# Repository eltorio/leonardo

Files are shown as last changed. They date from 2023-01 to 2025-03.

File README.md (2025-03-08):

# Leonardo
Arduino Leonardo schematic ported to Kicad

# Star the project

**If you appreciate my work, please consider giving it a star! 🤩**

# Kicad 8
The design has been ported to Kicad 8.  
* DRC shows no error nor warning on PCB.
* All selected parts are easily availables.
* All parts contains 3 additional fields
    * Manufacturer containing the name of the manufacturer
    * Manufacturer_ref containing the part real reference
    * Digikey_ref containing a Digikey part number

NM, DNP parts are parts not mounted

# Why
Because I need to adapt the Leonardo design to include other functionalities my first work is to port the very good Arduino Leonardo rev3d to Kicad 6.  

# Crystal
16MHz Crystal is not yet selected…

# Schematic
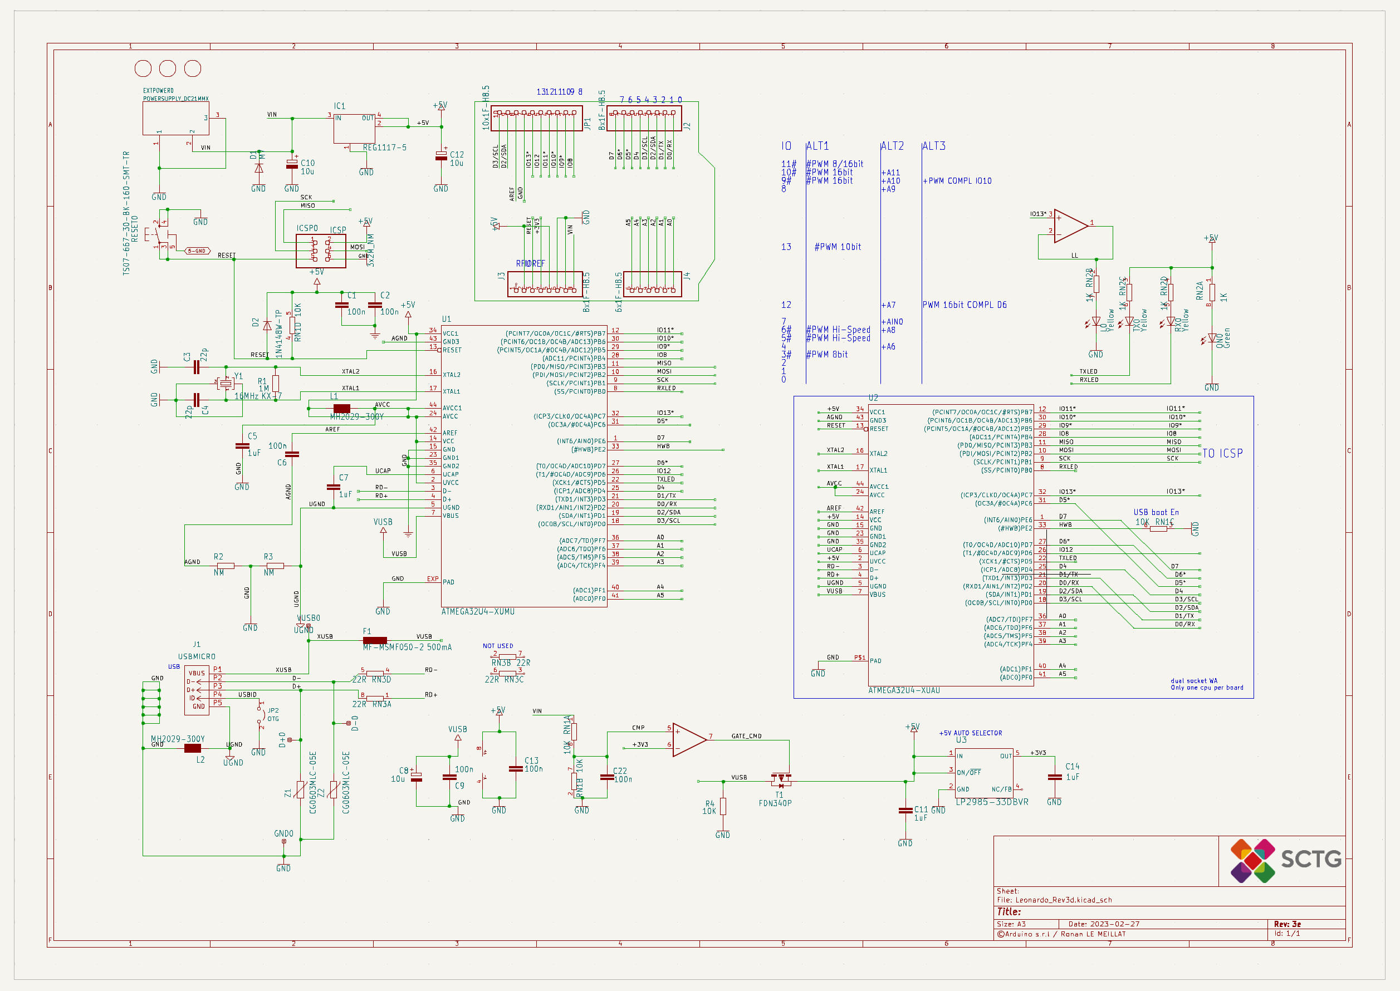
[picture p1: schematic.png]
Schematic


# Board
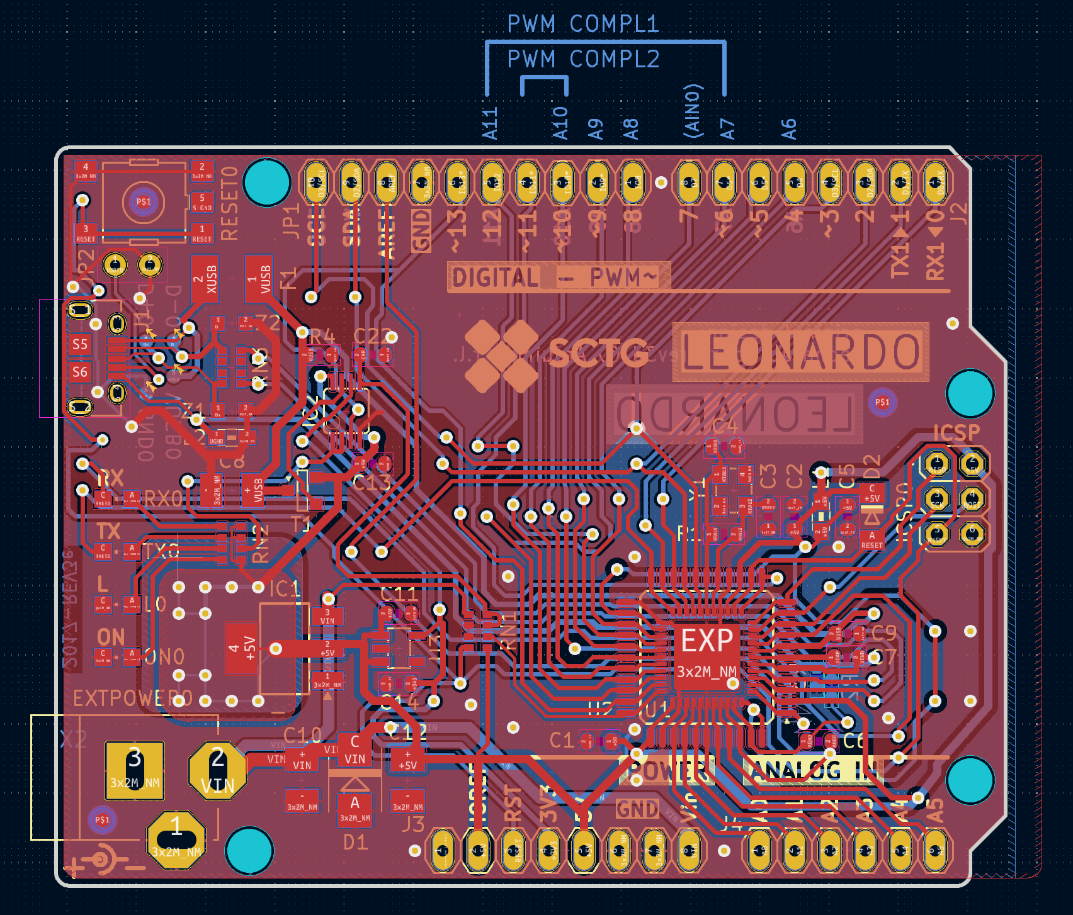
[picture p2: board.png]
Board

The board is adapted and routed with the parts I have selected.  
Kicad 8 DRC check doesn't show any errors nor any warning.  
Component references are hidden by default to match the Arduino Leonardo silkscreen. If you need the references, use the [Hide References plugin](https://github.com/joelsa/kicad-hide-references-plugin) which can be easily installed via the Plugin and Content Manager.

# 3D Render

## Without component references
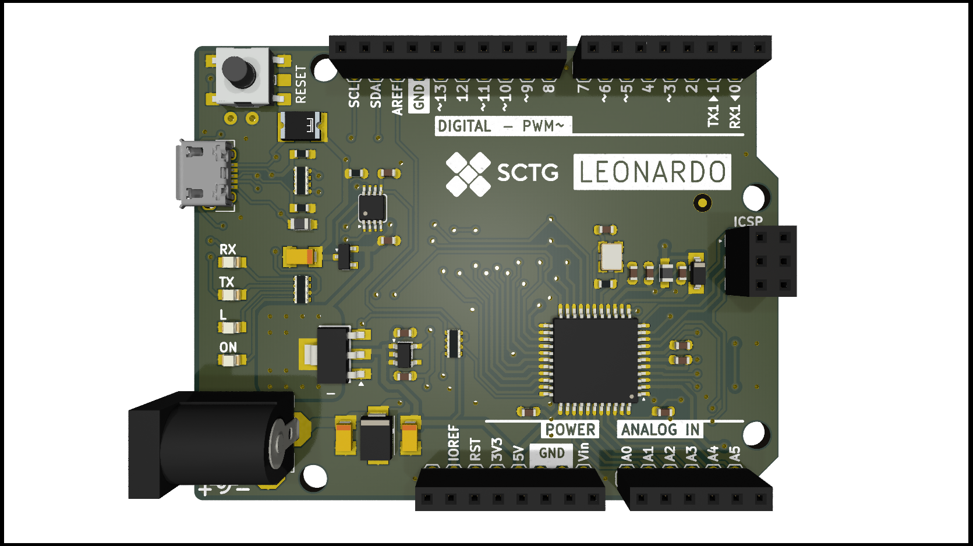
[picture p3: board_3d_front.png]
Front without component references


## With component references
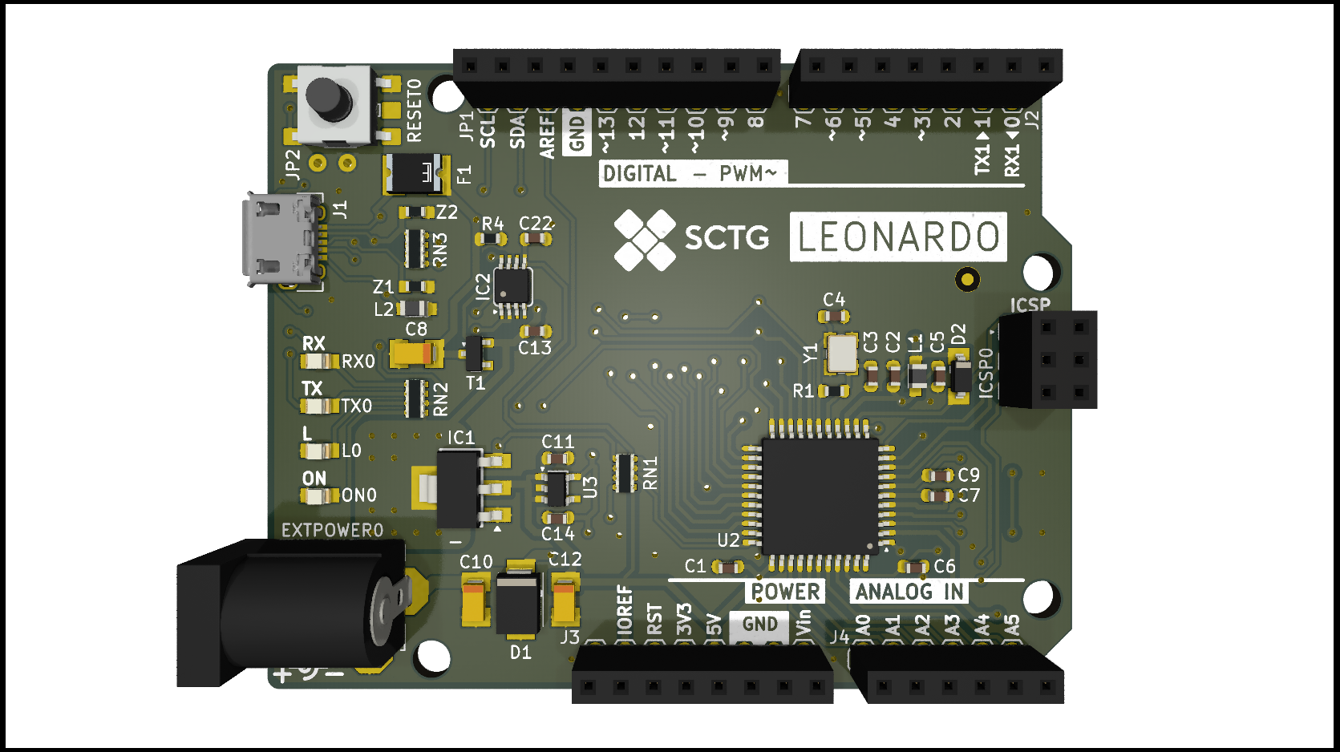
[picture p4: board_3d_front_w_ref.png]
Front with component references


# BOM
The [BOM](https://raw.githubusercontent.com/eltorio/leonardo/main/Leonardo_Rev3e.html) was automatically generated with [python/bom.py](https://github.com/eltorio/leonardo/blob/main/python/bom.py) add this script in the BOM dialog.  
The html BOM was converted to MarkDown with https://www.convertsimple.com/convert-html-to-markdown/   

[comment]: <> (generated from html bom with https://www.convertsimple.com/convert-html-to-markdown/)  
**Component Count: 56**

| Ref | Qnty | Value | Footprint | Datasheet | Manufacturer | Manufacturer_ref | Digikey_ref |
| --- | --- | --- | --- | --- | --- | --- | --- |
| C1, C2, C6, C9, C13, C22 | 6 | 100n | Leonardo_Rev3e:C0603-ROUND | [link](https://connect.kemet.com:7667/gateway/IntelliData-ComponentDocumentation/1.0/download/datasheet/C0603C104J4RACTU) | Kemet | C0603C104J4RAC7867 | [399-C0603C104J4RAC7867CT-ND](https://www.digikey.com/en/products?mpart=399-C0603C104J4RAC7867CT-ND) |
| C3, C4 | 2 | 22p | Leonardo_Rev3e:C0603-ROUND | [link](https://connect.kemet.com:7667/gateway/IntelliData-ComponentDocumentation/1.0/download/datasheet/C0603C220K5RAC7867) | Kemet | C0603C220K5RAC7867 | [399-14962-1-ND](https://www.digikey.com/en/products?mpart=399-14962-1-ND) |
| C5, C7, C11, C14 | 4 | 1uF | Leonardo_Rev3e:C0603-ROUND | [link](https://connect.kemet.com:7667/gateway/IntelliData-ComponentDocumentation/1.0/download/datasheet/C0603C105K4RAC7411) | Kemet | C0603C105K4RAC7411 | [399-C0603C105K4RAC7411CT-ND](https://www.digikey.com/en/products?mpart=399-C0603C105K4RAC7411CT-ND) |
| C8, C10, C12 | 3 | 10u | Leonardo\_Rev3d:SMC\_B | [link](https://api.kemet.com/component-edge/download/datasheet/T491B106M016AT.pdf) | Kemet | T491B106M016AT | [399-3708-1-ND](https://www.digikey.com/en/products?mpart=399-3708-1-ND) |
| D1  | 1 | M7  | Leonardo_Rev3e:SMB | | | | |
| D2  | 1 | 1N4148W-TP | Leonardo_Rev3e:MINIMELF | [link](https://www.mccsemi.com/pdf/Products/1N4148W(SOD-123).pdf) | MCC | 1N4148W-TP | [1N4148WTPMSCT-ND](https://www.digikey.com/en/products?mpart=1N4148WTPMSCT-ND) |
| D+0 | 1 | DNP | Leonardo_Rev3e:TP-1.00MM | | | | |
| D-0 | 1 | DNP | Leonardo_Rev3e:TP-1.00MM | | | | |
| EXTPOWER0 | 1 | POWERSUPPLY_DC21MMX | Leonardo\_Rev3d:POWERSUPPLY\_DC-21MM | | | | |
| F1  | 1 | MF-MSMF050-2 500mA | Leonardo_Rev3e:L1812 | [link](https://www.bourns.com/docs/product-datasheets/mf-msmf.pdf) | Bourns | MF-MSMF050-2 | [MF-MSMF050-2CT-ND](https://www.digikey.com/en/products?mpart=MF-MSMF050-2CT-ND) |
| FID1, FID2, FID3 | 3 | DNP | Leonardo_Rev3e:FD-1-1.5 | | | | |
| GND0 | 1 | DNP | Leonardo_Rev3e:TP-1.00MM | | | | |
| IC1 | 1 | REG1117-5 | Leonardo_Rev3e:SOT223 | [link](https://www.ti.com/lit/gpn/reg1117) | TI  | REG1117-5 | [REG1117-5-ND](https://www.digikey.com/en/products?mpart=REG1117-5-ND) |
| IC2 | 1 | LMV358IDGKR | Leonardo_Rev3e:MSOP08 | [link](https://www.ti.com/lit/gpn/lmv358) | TI  | 296-13455-1-ND | [LMV358IDGKR](https://www.digikey.com/en/products?mpart=LMV358IDGKR) |
| ICSP0 | 1 | ICSP | Leonardo_Rev3e:2X03 | [link](https://www.te.com/commerce/DocumentDelivery/DDEController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) | TE  | 5-146486-3 | [A128860-ND](https://www.digikey.com/en/products?mpart=A128860-ND) |
| J1  | 1 | USBMICRO | Leonardo_Rev3e:10118194-0001LF | [link](https://www.amphenol-cs.com/media/wysiwyg/files/drawing/10118194.pdf) | Amphenol | 10118194-0001LF | [609-4618-1-ND](https://www.digikey.com/en/products?mpart=609-4618-1-ND) |
| J2, J3 | 2 | 8x1F-H8.5 | Leonardo_Rev3e:1X08 | [link](https://media.digikey.com/pdf/Data%20Sheets/Sullins%20PDFs/Female_Headers.100_DS.pdf) | Sullins | PPPC081LFBN-RC | [S7041-ND](https://www.digikey.com/en/products?mpart=S7041-ND) |
| J4  | 1 | 6x1F-H8.5 | Leonardo_Rev3e:1X06 | [link](https://media.digikey.com/pdf/Data%20Sheets/Sullins%20PDFs/Female_Headers.100_DS.pdf) | Sullins | PPPC061LFBN-RC | [S7039-ND](https://www.digikey.com/en/products?mpart=S7039-ND) |
| JP1 | 1 | 10x1F-H8.5 | Leonardo_Rev3e:1X10 | [link](https://media.digikey.com/pdf/Data%20Sheets/Sullins%20PDFs/Female_Headers.100_DS.pdf) | Sullins | PPPC101LFBN-RC | [S7043-ND](https://www.digikey.com/en/products?mpart=S7043-ND) |
| JP2 | 1 | OTG | Leonardo\_Rev3d:HEADER\_2_2.54 | [link](~) | Samtex | DW-02-07-T-S-200 | [SAM15134-ND](https://www.digikey.com/en/products?mpart=SAM15134-ND) |
| L0  | 1 | Yellow | Leonardo\_Rev3d:CHIPLED\_0805 | [link](https://optoelectronics.liteon.com/upload/download/DS22-2000-110/LTST-C171KSKT.pdf) | Lite-on | LTST-C171KSKT | [160-1428-1-ND](https://www.digikey.com/en/products?mpart=160-1428-1-ND) |
| L1, L2 | 2 | MH2029-300Y | Leonardo_Rev3e:0805 | [link](https://www.bourns.com/docs/Product-Datasheets/mh.pdf) | Bourns | MH2029-300Y | [MH2029-300YCT-ND](https://www.digikey.com/en/products?mpart=MH2029-300YCT-ND) |
| ON0 | 1 | Green | Leonardo\_Rev3d:CHIPLED\_0805 | [link](https://optoelectronics.liteon.com/upload/download/DS22-2000-110/LTST-C171KSKT.pdf) | Lite-on | LTST-C171KGKT | [160-1426-1-ND](https://www.digikey.com/en/products?mpart=160-1426-1-ND) |
| R1  | 1 | 1M  | Leonardo_Rev3e:R0603-ROUND | [link](https://www.bourns.com/docs/product-datasheets/cr.pdf?sfvrsn=574d41f6_14) | Bourns | CR0603-FX-1004ELF | [CR0603-FX-1004ELFCT-ND](https://www.digikey.com/en/products?mpart=CR0603-FX-1004ELFCT-ND) |
| R2, R3 | 2 | NM  | Leonardo_Rev3e:R0402 | | | | |
| R4  | 1 | 10K | Leonardo_Rev3e:R0603-ROUND | [link](https://www.bourns.com/docs/product-datasheets/cr.pdf?sfvrsn=574d41f6_14) | Bourns | CR0603-FX-1002ELF | [CR0603-FX-1002ELFCT-ND](https://www.digikey.com/en/products?mpart=CR0603-FX-1002ELFCT-ND) |
| RESET0 | 1 | TS07-667-30-BK-160-SMT-TR | Leonardo_Rev3e:TS07 | [link](https://www.cuidevices.com/product/resource/ts07.pdf) | CUI | TS07-667-30-BK-160-SMT-TR | [2223-TS07-667-30-BK-160-SMT-TRCT-ND](https://www.digikey.com/en/products?mpart=2223-TS07-667-30-BK-160-SMT-TRCT-ND) |
| RN1 | 1 | 10K | Leonardo_Rev3e:CAY16 | [link](https://www.bourns.com/docs/Product-Datasheets/CATCAY.pdf) | Bourns | CAY16-1002F4LF | [CAY16-1002F4LFCT-ND](https://www.digikey.com/en/products?mpart=CAY16-1002F4LFCT-ND) |
| RN2 | 1 | 1K  | Leonardo_Rev3e:CAY16 | [link](https://www.bourns.com/docs/Product-Datasheets/CATCAY.pdf) | Bourns | CAY16-1001F4LF | [CAY16-1001F4LFCT-ND](https://www.digikey.com/en/products?mpart=CAY16-1001F4LFCT-ND) |
| RN3 | 1 | 22R | Leonardo_Rev3e:CAY16 | [link](https://www.bourns.com/docs/Product-Datasheets/CATCAY.pdf) | Bourns | CAY16-22R0F4LF | [CAY16-22R0F4LFCT-ND](https://www.digikey.com/en/products?mpart=CAY16-22R0F4LFCT-ND) |
| RX0 | 1 | Yellow | Leonardo\_Rev3d:CHIPLED\_0805 | [link](https://optoelectronics.liteon.com/upload/download/DS22-2000-110/LTST-C171KSKT.pdf) | Lite-on | LTST-C171KSKT | [160-1426-1-ND](https://www.digikey.com/en/products?mpart=160-1426-1-ND) |
| T1  | 1 | FDN340P | Leonardo_Rev3e:SOT-23 | [link](https://media.digikey.com/pdf/Data%20Sheets/UTD%20Semi%20PDFs/UMW%20FDN340P.pdf) | UMW | FDN340P | [4518-FDN340PCT-ND](https://www.digikey.com/en/products?mpart=4518-FDN340PCT-ND) |
| TX0 | 1 | Yellow | Leonardo\_Rev3d:CHIPLED\_0805 | [link](https://optoelectronics.liteon.com/upload/download/DS22-2000-110/LTST-C171KSKT.pdf) | Lite-on | LTST-C171KSKT | [160-1426-1-ND](https://www.digikey.com/en/products?mpart=160-1426-1-ND) |
| U1  | 1 | ATMEGA32U4-XUMU | Leonardo_Rev3e:QFN44ML7X7 | [link](http://ww1.microchip.com/downloads/en/DeviceDoc/Atmel-7766-8-bit-AVR-ATmega16U4-32U4_Summary.pdf) | Microchip | ATMEGA32U4-MU | [ATMEGA32U4-MU-ND](https://www.digikey.com/en/products?mpart=ATMEGA32U4-MU-ND) |
| U2  | 1 | ATMEGA32U4-XUAU | Leonardo_Rev3e:TQFP44-PAD | [link](http://ww1.microchip.com/downloads/en/DeviceDoc/Atmel-7766-8-bit-AVR-ATmega16U4-32U4_Summary.pdf) | Microchip | ATMEGA32U4-AU | [ATMEGA32U4-AU-ND](https://www.digikey.com/en/products?mpart=ATMEGA32U4-AU-ND) |
| U3  | 1 | LP2985-33DBVR | Leonardo_Rev3e:SOT23-DBV | [link](https://www.ti.com/lit/gpn/LP2985-N) | TI  | LP2985IM5-3.3 | [LP2985IM5-3.3CT-ND](https://www.digikey.com/en/products?mpart=LP2985IM5-3.3CT-ND) |
| VUSB0 | 1 | DNP | Leonardo_Rev3e:TP-1.00MM | | | | |
| Y1  | 1 | 16MHz KX-7 | Leonardo_Rev3e:CRYSTAL-3.2-2.5 | | | | |
| Z1, Z2 | 2 | CG0603MLC-05E | Leonardo\_Rev3d:CT\_CN0603 | [link](https://www.bourns.com/docs/product-datasheets/cga-mlc.pdf) | Bourns | CG0603MLC-05E | [CG0603MLC-05ECT-ND](https://www.digikey.com/en/products?mpart=CG0603MLC-05ECT-ND) |

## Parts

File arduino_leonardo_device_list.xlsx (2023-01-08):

Part Correlation(s) | Qty | Value | Brand | Manufacturer | Digikey | Description | Device
C1,C2,C6,C9,C13,C22 | 6 | 100n | Kemet | C0603C104J4RAC7867 | 399-C0603C104J4RAC7867CT-ND | 100nF Capacitor | C-EUC0603
RN2 | 1 | 1K | Bourns | CAY16-1001F4LF | CAY16-1001F4LFCT-ND | 1K Ohm Resistor | 4R-NCAY16
RN1 | 1 | 10K | Bourns | CAY16-1002F4LF | CAY16-1002F4LFCT-ND | 10K Ohm Resistor | 4R-NCAY16
Z1,Z2 | 2 | CG0603MLC-05E | Bourns | CG0603MLC-05E | CG0603MLC-05ECT-ND | Bourns CG0603MLC-05E Varistor | VARISTORCN0603
RN3 | 1 | 22R | Bourns | CAY16-22R0F4LF | CAY16-22R0F4LFCT-ND | 22 Ohm Resistor | 4R-NCAY16
L,RX,TX | 3 | Yellow | Lite-On | LTST-C171KSKT | 160-1428-1-ND | Yellow LED | LEDCHIPLED_0805
ON | 1 | Green | Lite-On | LTST-C171KGKT | 160-1426-1-ND | Green LED | LEDCHIPLED_0805
C3,C4 | 2 | 22p | Kemet | C0603C220K5RAC7867 | 399-14962-1-ND | 22pF Capacitor | C-EUC0603
C5,C7,C11,C14 | 4 | 1uF | Kemet | C0603C105K4RAC7411 | 399-C0603C105K4RAC7411CT-ND | 1uF Capacitor | C-EUC0603
R1 | 1 | 1M | Bourns | CR0603-FX-1004ELF | CR0603-FX-1004ELFCT-ND | 1M Ohm Resistor | R-EU_R0603
J2,J3 | 2 | 8x1F-H8.5 | Sullins | PPPC081LFBN-RC | S7041-ND | 1x8 Pin Header | PINHD-1X8
J4 | 1 | 6x1F-H8.5 | Sullins | PPPC061LFBN-RC | S7039-ND | 1x6 Pin Header | PINHD-1X6
JP1 | 1 | 10x1F-H8.5 | Sullins | PPPC101LFBN-RC | S7043-ND | 1x10 Pin Head | PINHD-1X10
ICSP | 1 | ICSP | TE | 5-146486-3 | A128860-ND | 2x3 Pin Header | PINHD-2X3
T1 | 1 | FDN340P | UMW | FDN340P | 4518-FDN340PCT-ND | MOS FET FDN340P (semiconductor) | PMOSSOT23
Y1 | 1 | 16MHz KX-7 |  |  |  | 16MHz Quartz Crystal | CRYSTAL-3.2-2.5 | Value mentions KX-7. Specs at crystal%20kx%207
C8,C10,C12 | 3 | 10u | Kemet | T491B106M016AT | 399-3708-1-ND | 10uF Polarized Capacitor | CPOL-EUSMCB
D2 | 1 | CD1206-S01575 | MCC | 1N4148W-TP | 1N4148WTPMSCT-ND | Diode standard 100V/150mA | DIODE-MINIMELF
U3 | 1 | LP2985-33DBVR | TI | LP2985IM5-3.3 | LP2985IM5-3.3CT-ND | LP2985-33DBVR Low Dropout Regulator | LP2985-XXDBVR33
IC1 | 1 | NCP1117ST50T3G | TI | REG1117-5 | REG1117-5-ND | NCP1117ST50T3G Low Dropout Regulator (Positive) | MC33269ST-3.3T3
L1,L2 | 2 | MH2029-300Y | Bourns | MH2029-300Y | MH2029-300YCT-ND | Bourns MH2029-300Y Ferrite Beads | MH2029-300Y
F1 | 1 | MF-MSMF050-2 500mA | Bourns | MF-MSMF050-2 | MF-MSMF050-2CT-ND | Bourns L-EUL1812 PTC Resettable Fuse | L-EUL1812 | 500mA refers to the “hold” rate, which the model has
J1 | 1 | USB MICRO | Amphenol | 10118194-0001LF | 609-4618-1-ND | Type B Micro USB Connector | MYCON2_USB-MINI-B
IC2 | 1 | LMV358MMX | TI | LMV358IDGKR | 296-13455-1-ND | LMV358MMX Operational Amplifier | LMV358IDGKR
U1* | 1 | ATMEGA32U4-XUMU | Microchip | ATMEGA32U4-MU | ATMEGA32U4-MU-ND | atmega32u4-mu MCU | ATMEGA32U4-XUMU | * Only one ever on a single board
U2* | 1 | ATMEGA32U4-XUAU | Microchip | ATMEGA32U4-AU | ATMEGA32U4-AU-ND | atmega32u4-au | ATMEGA32U4-XUAU
EXTPOWER | 1 | Not mounted |  |  |  | 2.1mm DC Connector | POWERSUPPLY_DC21MMX
R2,R3 | 2 | Not mounted |  |  |  | Resistor? | R-EU_R0402 | Don't know the resistance. Can't find on board. Could be a capacitor according to http://www.arduino.cc/cgi-bin/yabb2/YaBB.pl?num=1223532015
D1 | 1 | Not mounted |  |  |  | Diode Rectifier | DIODE-SMB | SMB refers to the mount style, but M7, whatever that means, seems only available for the SMD mounting style
RESET | 1 | TS42 | CUI | TS07-667-30-BK-160-SMT-TR |  | Tactile Switch | TS42 | Not sure what the 42 refers to. Maybe a dimension (i.e. 4.2mm)?
JP2 | 1 | OTG Header | Samtex | DW-02-07-T-S-200 | SAM15134-ND | Jumper | JP2

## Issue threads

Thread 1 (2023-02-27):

Pin1 of the ATmega32U4 is incorrectly connected to pin33

dcelectr, 2023-02-27:
During the import the diagonal line of net D7 was close to RN1C
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
See how it is in the PDF
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
Also in the Eagle layout the Pin 33  ATmega32U4 goes only to RN1C
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

eltorio, 2023-02-27:
Thanks,
Corrected in e10cf282fa710b1ea3066e1623296bcfc7b7702d

Closed 2023-02-27.

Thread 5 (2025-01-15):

AVCC direct connection to VCC

twildi, 2025-01-15:
There is mistake in the schematic : the analogue voltage reference AVCC should be isolated from VCC as the AVR hardware design guidelines specify (https://ww1.microchip.com/downloads/en/appnotes/atmel-2521-avr-hardware-design-considerations_applicationnote_avr042.pdf).

In the current schematic AVCC is shorted to VCC, which is wrong (notice that L1 is shorted):
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

I think this mistakes stems from the poor schematic from Arduino themself (https://docs.arduino.cc/resources/schematics/A000057-schematics.pdf).
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

An older version of the schematic is much clearer (https://www.arduino.cc/en/uploads/Main/arduino-leonardo-schematic_3b.pdf) :
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

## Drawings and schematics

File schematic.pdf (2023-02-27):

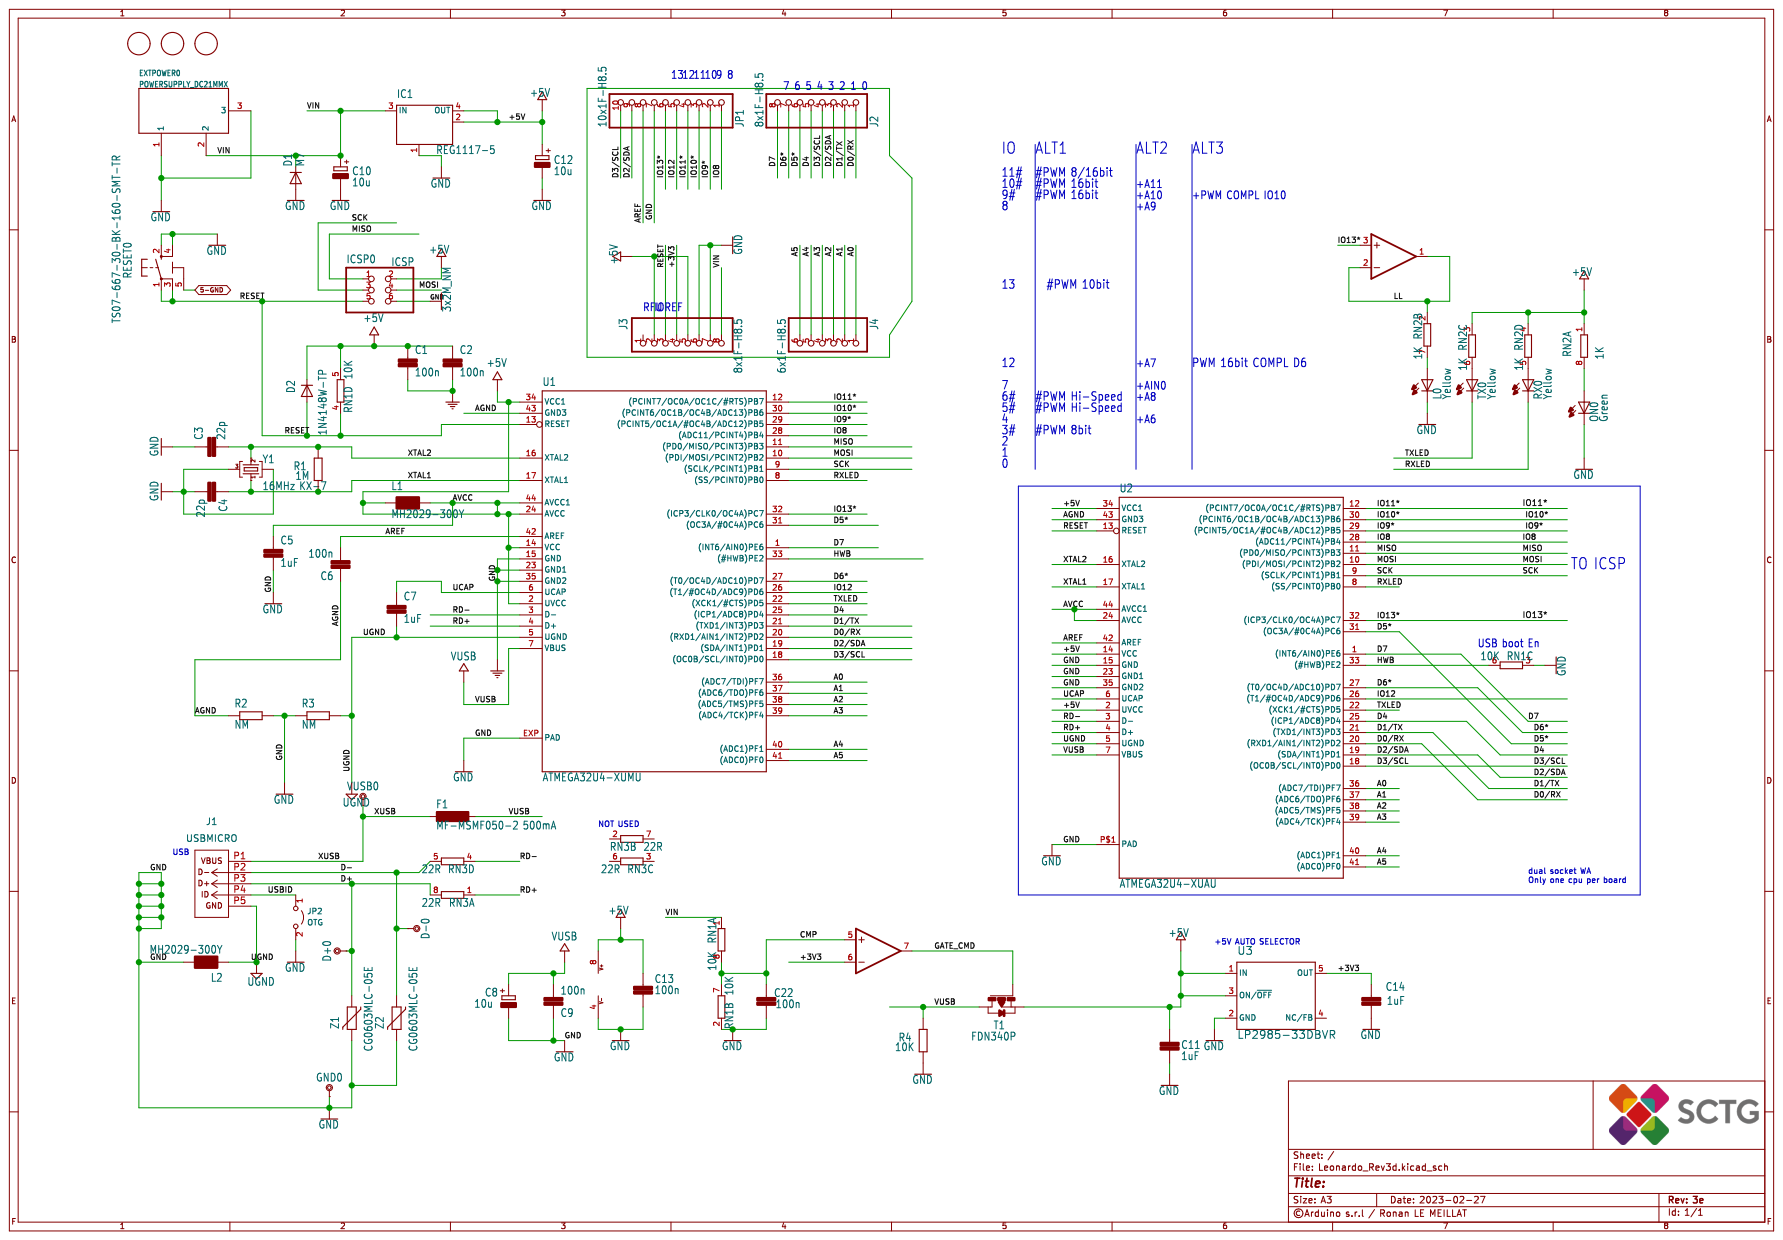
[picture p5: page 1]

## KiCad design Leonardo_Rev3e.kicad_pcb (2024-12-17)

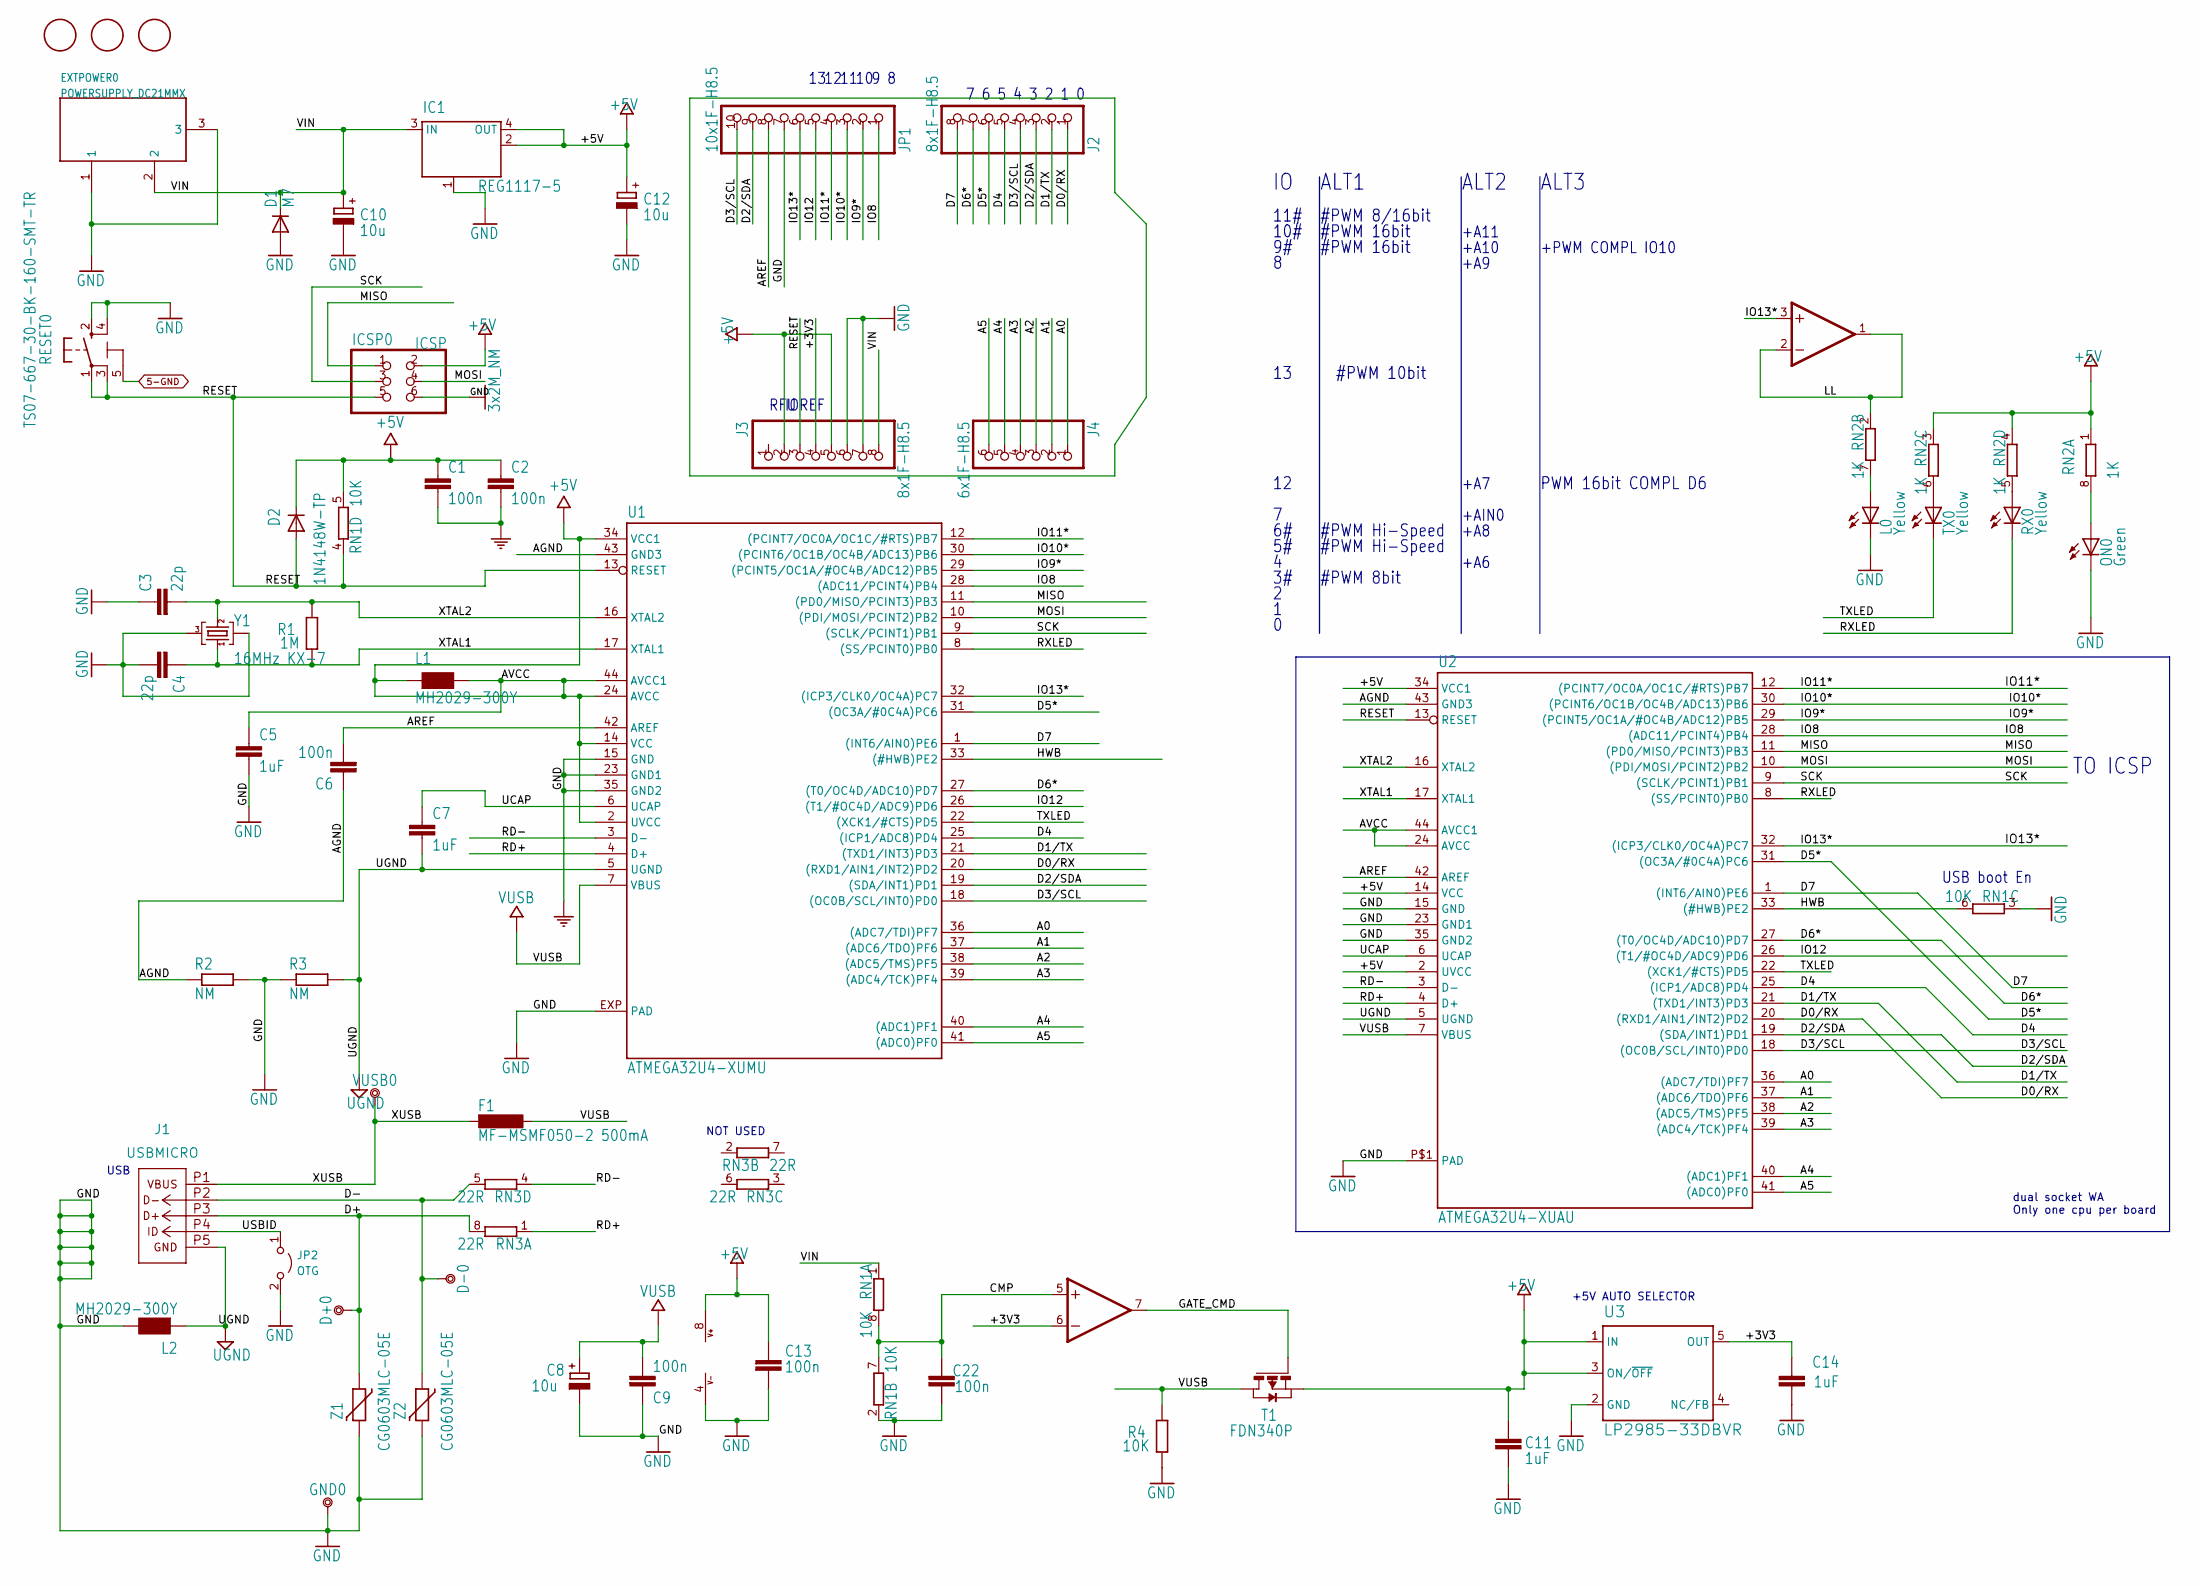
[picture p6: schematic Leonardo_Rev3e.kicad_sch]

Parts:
C1, C2, C6, C9, C13, C22: 100n; C0603-ROUND; Digikey_ref 399-C0603C104J4RAC7867CT-ND
C3, C4: 22p; C0603-ROUND; Digikey_ref 399-14962-1-ND
C5, C7, C11, C14: 1uF; C0603-ROUND; Digikey_ref 399-C0603C105K4RAC7411CT-ND
C8, C10, C12: 10u; SMC_B; Digikey_ref 399-3708-1-ND
D1: M7; SMB
D2: 1N4148W-TP; MINIMELF; Digikey_ref 1N4148WTPMSCT-ND
D+0: DNP; TP-1.00MM
D-0: DNP; TP-1.00MM
EXTPOWER0: POWERSUPPLY_DC21MMX; POWERSUPPLY_DC-21MM
F1: MF-MSMF050-2 500mA; L1812; Digikey_ref MF-MSMF050-2CT-ND
FID1, FID2, FID3: DNP; FD-1-1.5
GND0: DNP; TP-1.00MM
IC1: REG1117-5; SOT223; Digikey_ref REG1117-5-ND
IC2: LMV358IDGKR; MSOP08; Digikey_ref LMV358IDGKR
ICSP0: ICSP; 2X03; Digikey_ref A128860-ND
J1: USBMICRO; 10118194-0001LF; Digikey_ref 609-4618-1-ND
J2, J3: 8x1F-H8.5; 1X08; Digikey_ref S7041-ND
J4: 6x1F-H8.5; 1X06; Digikey_ref S7039-ND
JP1: 10x1F-H8.5; 1X10; Digikey_ref S7043-ND
JP2: OTG; HEADER_2_2.54; Digikey_ref SAM15134-ND
L0: Yellow; CHIPLED_0805; Digikey_ref 160-1428-1-ND
L1, L2: MH2029-300Y; 0805; Digikey_ref MH2029-300YCT-ND
ON0: Green; CHIPLED_0805; Digikey_ref 160-1426-1-ND
R1: 1M; R0603-ROUND; Digikey_ref CR0603-FX-1004ELFCT-ND
R2, R3: NM; R0402
R4: 10K; R0603-ROUND; Digikey_ref CR0603-FX-1002ELFCT-ND
RESET0: TS07-667-30-BK-160-SMT-TR; TS07; Digikey_ref 2223-TS07-667-30-BK-160-SMT-TRCT-ND
RN1: 10K; CAY16; Digikey_ref CAY16-1002F4LFCT-ND
RN2: 1K; CAY16; Digikey_ref CAY16-1001F4LFCT-ND
RN3: 22R; CAY16; Digikey_ref CAY16-22R0F4LFCT-ND
RX0: Yellow; CHIPLED_0805; Digikey_ref 160-1426-1-ND
T1: FDN340P; SOT-23; Digikey_ref 4518-FDN340PCT-ND
TX0: Yellow; CHIPLED_0805; Digikey_ref 160-1426-1-ND
U1: ATMEGA32U4-XUMU; QFN44ML7X7; Digikey_ref ATMEGA32U4-MU-ND
U2: ATMEGA32U4-XUAU; TQFP44-PAD; Digikey_ref ATMEGA32U4-AU-ND
U3: LP2985-33DBVR; SOT23-DBV; Digikey_ref LP2985IM5-3.3CT-ND
VUSB0: DNP; TP-1.00MM
Y1: 16MHz KX-7; CRYSTAL-3.2-2.5
Z1, Z2: CG0603MLC-05E; CT_CN0603; Digikey_ref CG0603MLC-05ECT-ND

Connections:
3x2M_NM: C1.2, C2.2, C3.1, C4.2, C5.2, C8.-, C9.1, C10.-, C11.1, C12.-, C13.2, C14.1, C22.1, D1.A, EXTPOWER0.1, EXTPOWER0.3, GND0.X, IC1.1 (GND/ADJ), IC2.4 (V-), ICSP0.6, J3.6, J3.7, JP1.7, JP2.2 (B), L0.C, L2.2, ON0.C, R2.2, R3.1, R4.1, RESET0.2, RESET0.4, RN1.2 (1), RN1.3 (1), U1.15 (GND), U1.23 (GND1), U1.35 (GND2), U1.EXP (PAD), U2.15 (GND), U2.23 (GND1), U2.35 (GND2), U2.P$1 (PAD), U3.2 (GND), Y1.2 (GND@1), Y1.4 (GND@2), Z1.2, Z2.2
5-GND: RESET0.5 (5-GND)
+5V: C1.1, C2.1, C5.1, C11.2, C12.+, C13.1, D2.C, IC1.2 (OUT@1), IC1.4 (OUT), IC2.8 (V+), ICSP0.2, J3.2, J3.5, L1.1, L1.2, RN1.5 (2), RN2.1, RN2.3 (1), RN2.4 (1), T1.2 (S), U1.2 (UVCC), U1.14 (VCC), U1.24 (AVCC), U1.34 (VCC1), U1.44 (AVCC1), U2.2 (UVCC), U2.14 (VCC), U2.24 (AVCC), U2.34 (VCC1), U2.44 (AVCC1), U3.1 (IN), U3.3 (ON/~OFF)
/+3V3: C14.2, IC2.6 (-IN), J3.4, U3.5 (OUT)
/A0: J4.1, U1.36 ((ADC7/TDI)PF7), U2.36 ((ADC7/TDI)PF7)
/A1: J4.2, U1.37 ((ADC6/TDO)PF6), U2.37 ((ADC6/TDO)PF6)
/A2: J4.3, U1.38 ((ADC5/TMS)PF5), U2.38 ((ADC5/TMS)PF5)
/A3: J4.4, U1.39 ((ADC4/TCK)PF4), U2.39 ((ADC4/TCK)PF4)
/A4: J4.5, U1.40 ((ADC1)PF1), U2.40 ((ADC1)PF1)
/A5: J4.6, U1.41 ((ADC0)PF0), U2.41 ((ADC0)PF0)
/AGND: C6.1, R2.1, U1.43 (GND3), U2.43 (GND3)
/AREF: C6.2, JP1.8, U1.42 (AREF), U2.42 (AREF)
/CMP: C22.2, IC2.5 (+IN), RN1.7 (2), RN1.8 (2)
/D0/RX: J2.1, U1.20 ((RXD1/AIN1/INT2)PD2), U2.20 ((RXD1/AIN1/INT2)PD2)
/D1/TX: J2.2, U1.21 ((TXD1/INT3)PD3), U2.21 ((TXD1/INT3)PD3)
/D2/SDA: J2.3, JP1.9, U1.19 ((SDA/INT1)PD1), U2.19 ((SDA/INT1)PD1)
/D3/SCL: J2.4, JP1.10, U1.18 ((OC0B/SCL/INT0)PD0), U2.18 ((OC0B/SCL/INT0)PD0)
/D4: J2.5, U1.25 ((ICP1/ADC8)PD4), U2.25 ((ICP1/ADC8)PD4)
/D5*: J2.6, U1.31 ((OC3A/#0C4A)PC6), U2.31 ((OC3A/#0C4A)PC6)
/D6*: J2.7, U1.27 ((T0/OC4D/ADC10)PD7), U2.27 ((T0/OC4D/ADC10)PD7)
/D7: J2.8, U1.1 ((INT6/AIN0)PE6), U2.1 ((INT6/AIN0)PE6)
/D+: D+0.X, J1.P3 (D+), RN3.8 (2), Z1.1
/D-: D-0.X, J1.P2 (D-), RN3.5 (2), Z2.1
/GATE_CMD: IC2.7 (OUT), T1.3 (G)
/HWB: RN1.6 (2), U1.33 ((#HWB)PE2), U2.33 ((#HWB)PE2)
/IO8: JP1.1, U1.28 ((ADC11/PCINT4)PB4), U2.28 ((ADC11/PCINT4)PB4)
/IO9*: JP1.2, U1.29 ((PCINT5/OC1A/#OC4B/ADC12)PB5), U2.29 ((PCINT5/OC1A/#OC4B/ADC12)PB5)
/IO10*: JP1.3, U1.30 ((PCINT6/OC1B/OC4B/ADC13)PB6), U2.30 ((PCINT6/OC1B/OC4B/ADC13)PB6)
/IO11*: JP1.4, U1.12 ((PCINT7/OC0A/OC1C/#RTS)PB7), U2.12 ((PCINT7/OC0A/OC1C/#RTS)PB7)
/IO12: JP1.5, U1.26 ((T1/#OC4D/ADC9)PD6), U2.26 ((T1/#OC4D/ADC9)PD6)
/IO13*: IC2.3 (+IN), JP1.6, U1.32 ((ICP3/CLK0/OC4A)PC7), U2.32 ((ICP3/CLK0/OC4A)PC7)
/LL: IC2.1 (OUT), IC2.2 (-IN), RN2.2 (1)
/MISO: ICSP0.1, U1.11 ((PD0/MISO/PCINT3)PB3), U2.11 ((PD0/MISO/PCINT3)PB3)
/MOSI: ICSP0.4, U1.10 ((PDI/MOSI/PCINT2)PB2), U2.10 ((PDI/MOSI/PCINT2)PB2)
/RD+: RN3.1, U1.4 (D+), U2.4 (D+)
/RD-: RN3.4 (1), U1.3 (D-), U2.3 (D-)
/RESET: D2.A, ICSP0.5, J3.3, RESET0.1, RESET0.3, RN1.4 (1), U1.13 (RESET), U2.13 (RESET)
/RXLED: RX0.C, U1.8 ((SS/PCINT0)PB0), U2.8 ((SS/PCINT0)PB0)
/SCK: ICSP0.3, U1.9 ((SCLK/PCINT1)PB1), U2.9 ((SCLK/PCINT1)PB1)
/TXLED: TX0.C, U1.22 ((XCK1/#CTS)PD5), U2.22 ((XCK1/#CTS)PD5)
/UCAP: C7.1, U1.6 (UCAP), U2.6 (UCAP)
/USBID: J1.P4 (ID), JP2.1 (A)
/VIN: C10.+, D1.C, EXTPOWER0.2, IC1.3 (IN), J3.8, RN1.1
/XTAL1: C4.1, R1.1, U1.17 (XTAL1), U2.17 (XTAL1), Y1.1 (C1)
/XTAL2: C3.2, R1.2, U1.16 (XTAL2), U2.16 (XTAL2), Y1.3 (C2)
/XUSB: F1.2, J1.P1 (VBUS), VUSB0.X
unnamed: ON0.A, RN2.8 (2)
unnamed: L0.A, RN2.7 (2)
unnamed: RN2.6 (2), TX0.A
unnamed: RN2.5 (2), RX0.A
UGND: C7.2, J1.P5 (GND), L2.1, R3.2, U1.5 (UGND), U2.5 (UGND)
VUSB: C8.+, C9.2, F1.1, R4.2, T1.1 (D), U1.7 (VBUS), U2.7 (VBUS)

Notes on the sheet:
#PWM 8/16bit
PWM 16bit COMPL D6
USB boot En
NOT USED
RFU
#PWM 8bit
+PWM COMPL IO10
#PWM 16bit
TO ICSP
dual socket WA Only one cpu per board
#PWM Hi-Speed
+A10
11#
IOREF
+5V AUTO SELECTOR
+AIN0
ALT3
+A8
+A9
ALT1
+A6
#PWM 10bit
USB
ALT2
10#
+A11
+A7

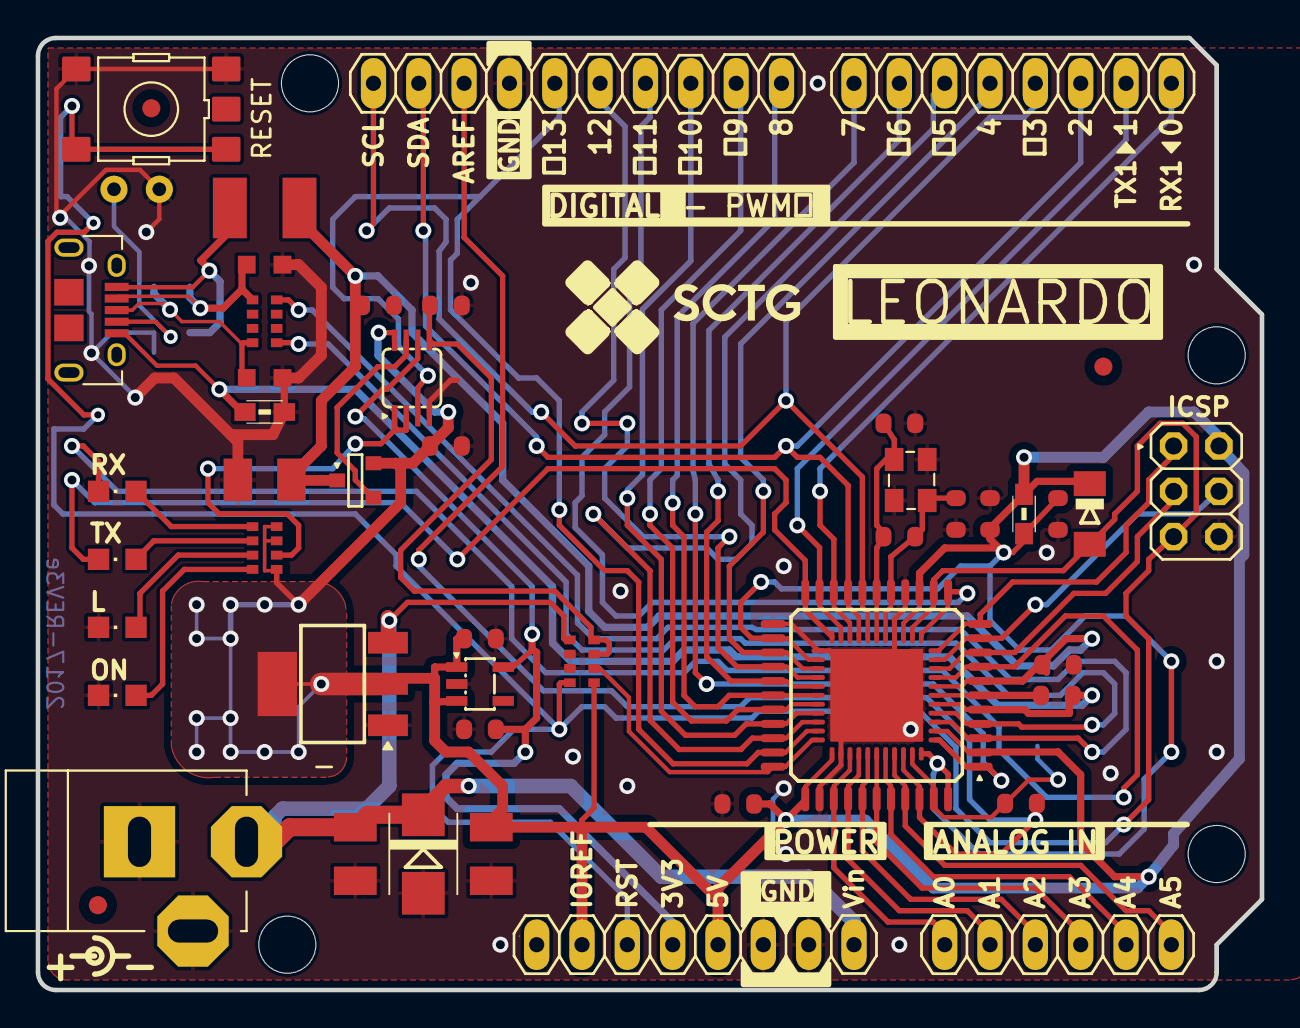
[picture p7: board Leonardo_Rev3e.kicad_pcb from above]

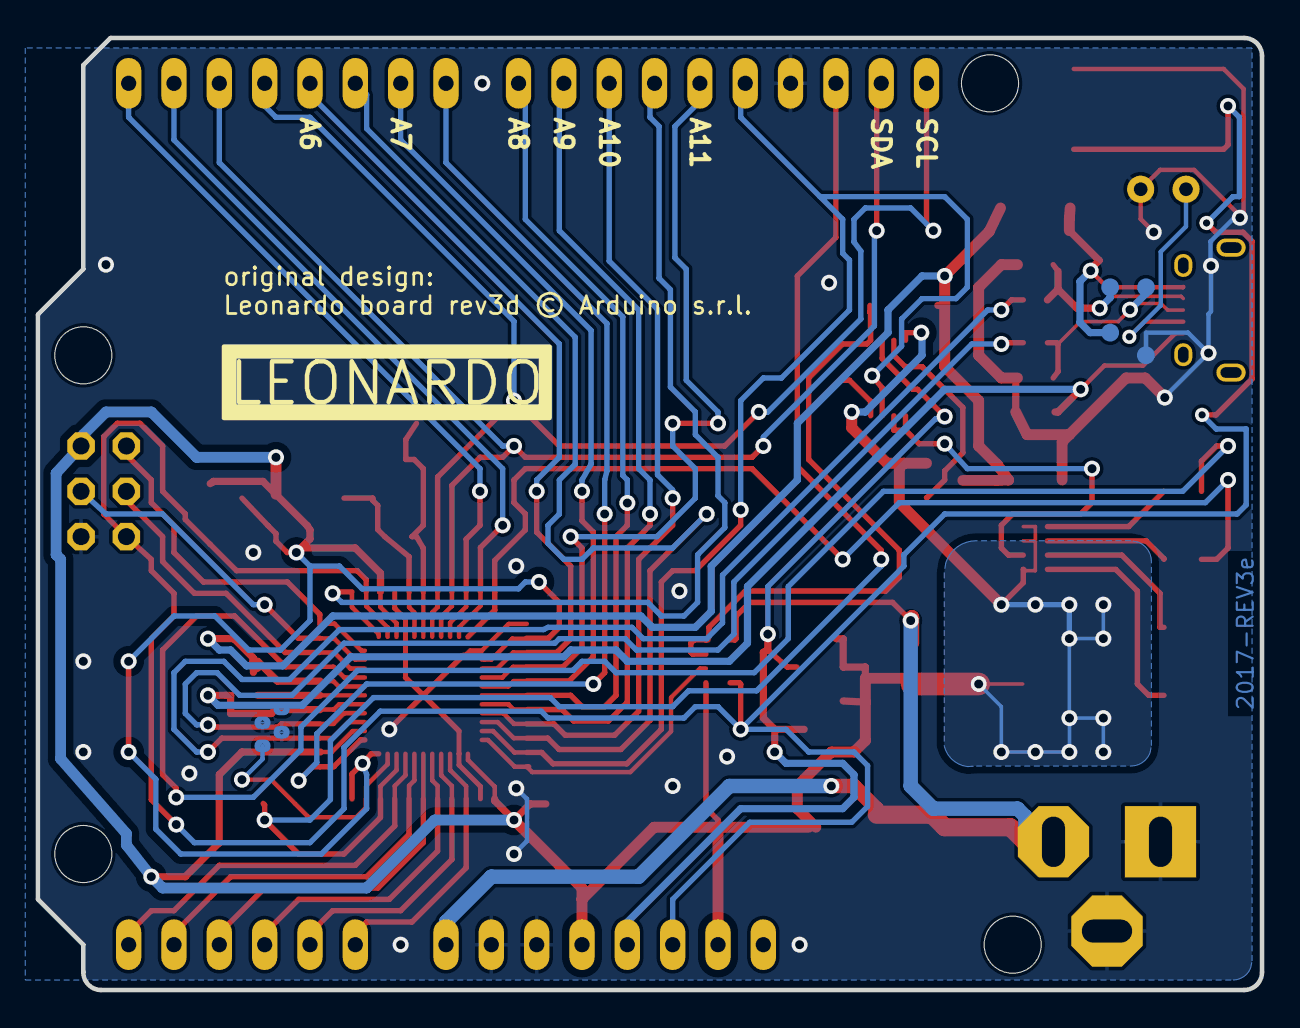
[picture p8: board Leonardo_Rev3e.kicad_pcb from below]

Board: 2 copper layers, 68.6 x 53.3 mm, 60 parts (2 on the bottom side), 51 nets.

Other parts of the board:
@HOLE0, @HOLE1, @HOLE2, @HOLE3: (no value)

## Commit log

2023-01-08 update version
    [Leonardo_Rev3d.kicad_pcb, Leonardo_Rev3d.kicad_sch, arduino_leonardo_device_list.xlsx]
2023-01-08 add fabrication
    [Leonardo_Rev3d-B_Cu.gbl, Leonardo_Rev3d-B_Cu.gbr, Leonardo_Rev3d-B_Mask.gbr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]
2023-01-08 Update documentation
    [Leonardo_Rev3d-B_Cu.gbl, Leonardo_Rev3d-B_Cu.gbr, Leonardo_Rev3d-B_Mask.gbr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]
2023-01-08 put schematic
2023-01-08 add link to schematic
2023-02-27 BUG: Correct D7/HWB error and upgrade to Kicad 7
    [Leonardo_Rev3d-B_Cu.gbl, Leonardo_Rev3d-B_Silkscreen.gbo, Leonardo_Rev3d-F_Cu.gtl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]
2024-12-17 chore: port to kicad 8
    [Leonardo_Rev3e.kicad_pcb, Leonardo_Rev3e.kicad_sch]
2024-12-17 feat: resize all references/text and match pin markings
    [Leonardo_Rev3e.kicad_pcb]
2024-12-17 chore: clean up footprint library
    [Leonardo_Rev3e.kicad_pcb]
2024-12-17 fix: move user comments to correct layer
    [Leonardo_Rev3e.kicad_pcb]
2024-12-17 feat: add labels to match original design
    [Leonardo_Rev3e.kicad_pcb]
2024-12-17 chore: clean up footprints and layout
    [Leonardo_Rev3e.kicad_pcb]
2024-12-17 chore: pass drc checks
    [Leonardo_Rev3e.kicad_pcb]
2024-12-17 chore: update board.png
2024-12-17 chore: clean up layout
    [Leonardo_Rev3e.kicad_pcb]
2024-12-17 fix: correct QFN44ML7X7 footprint
    [Leonardo_Rev3e.kicad_pcb]
2024-12-17 feat: add 3d models
    [Leonardo_Rev3e.kicad_pcb]
2024-12-17 chore: regenerate fabrication files
    [Leonardo_Rev3e-B_Cu.gbl, Leonardo_Rev3e-B_Mask.gbs, Leonardo_Rev3e-B_Paste.gbp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]

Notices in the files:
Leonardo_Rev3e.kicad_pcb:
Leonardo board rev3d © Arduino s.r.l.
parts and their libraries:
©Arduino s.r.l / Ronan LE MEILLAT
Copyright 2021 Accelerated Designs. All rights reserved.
